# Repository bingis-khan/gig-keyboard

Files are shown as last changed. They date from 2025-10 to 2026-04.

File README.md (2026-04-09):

# My split keyboard

my cool split keyboard. contains OpenSCAD source files and the arduino project file.

keyboard top
keyboard bottom

## Compiling

To generate the STL files, run `./print-script.sh`, which exports the STL part files.

For programming the board, use:

```
  arduino-cli compile -ub rp2040:rp2040:waveshare_rp2040_pizero -p /dev/ttyACM0
```

## Special mapping

- Soya button + hjkl - arrows
- Soya + top row - numbers
- Soya + 250mL + top row - Fn keys.
- 250mL (without Soya) - left alt
- juice key + -.'= keys - mouse movement.
- juice key + jk - scroll
- juice key + ,l/ - left/middle/right mouse button click

## Notes for V2

- use a pcb next time - wire crosstalk problems (actually, probably single copper strands touching each other)
- with a pcb, try adding how-swappable sockets.
- use linear switches

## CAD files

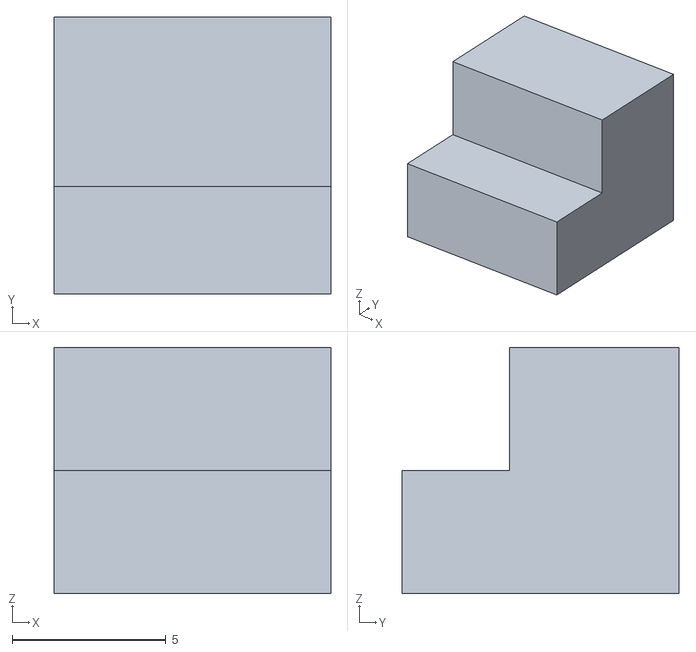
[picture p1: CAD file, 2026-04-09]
stl/third_leg.stl
9.00 x 9.00 x 8.00

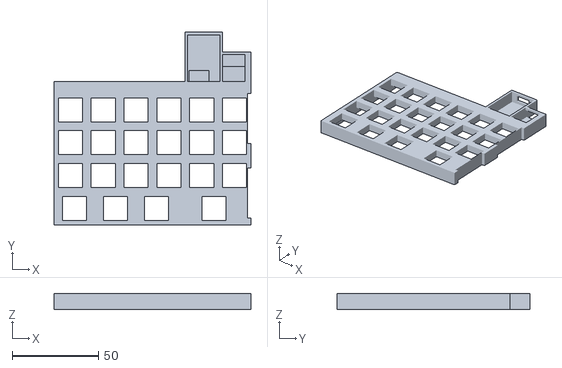
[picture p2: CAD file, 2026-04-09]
stl/left_part.stl
114.3 x 111.7 x 9.35

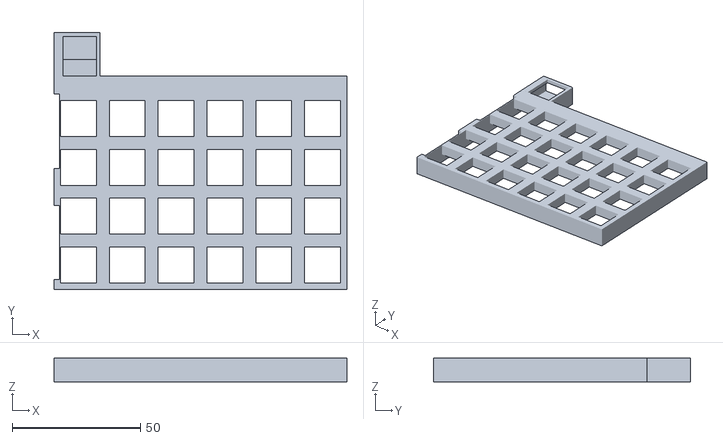
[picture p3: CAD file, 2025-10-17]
stl/right_part.stl
114.3 x 100.2 x 9.35

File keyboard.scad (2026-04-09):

$fa = 1;
$fs = 0.4;

print = false;  // may be redefined at command line


// right now, let's make a printable "slab" where I can insert the keys and put on keycaps to see if they fit.

// spacing: https://null-src.com/posts/keyboard-design-cheatsheet/
// apparently, 1u = 19.05mm

key_size = 14;
unit = 19.05;
key_pin = 3.3;  // from ref.
key_body = 5;
key_underside = key_pin + key_body;
key_off = (unit - key_size) / 2;

max_key_with_keycap_exact_height = 18;  // in mm. based on OEM num keys.
pressed_key_height = 11;  // close enough.
exposed_switch_height = 6;  // close enough
slump = exposed_switch_height;  // not sure how much to lower the keyboard plane. this variable tracks it.

// 2 parts. these numbers refer to one part.
keys_in_row = 6;
keys_in_column = 4;  // NOTE: last column is different.

use_width = keys_in_row * unit;
use_height = keys_in_column * unit;

cable_zone_height = 7;

off = 0;  // random offset, so that the part "sticks"

// if i decide to make the keyboard angled, this would be it.
key_plane_angle = 0;

avg_depth = 5;
cut_depth = 2;  // cutting shit


function sum(l, i = 0) =
    i < len(l)
        ? l[i] + sum(l, i + 1)
        : 0;

function slice(l, from, to) =
    to != undef  // HACK: if to is undefined, then we assume 'from' is actually 'to' and from is 0.
        ? to >= from  // when range is empty, make empty list yo.
            ? [for (i = [from : to]) l[i]]
            : []
        : slice(l, 0, from);

module key_plane_cutouts(edge_off, last_line) {
    key_begin = (unit - key_size) / 2;
    for (x = [key_begin : unit : use_width]) {
        // ignore closest key line
        for (y = [key_begin + unit : unit : use_height]) {
            translate([x + edge_off, y + edge_off, -cut_depth/2]) cube([key_size, key_size, avg_depth + cut_depth]);
        }
    }

    // add later lines
    last_line_units = [for (s = last_line) s * unit];
    for (i = [0 : len(last_line_units) - 1]) {
        spacing_until_now = sum(slice(last_line_units, i - 1));
        spacing = last_line_units[i];

        key_off = (spacing - key_size) / 2;

        x = edge_off + spacing_until_now + key_off;
        y = edge_off + key_begin;
        translate([x, y, -cut_depth/2]) cube([key_size, key_size, avg_depth + cut_depth]);
    }
}

module test_key_grid() {
    key_begin = (unit - key_size) / 2;
    for (x = [key_begin : unit : use_width]) {
        for (y = [key_begin : unit : use_height]) {
            translate([x + off, y + off, -cut_depth/2]) cube([key_size, key_size, avg_depth + cut_depth]);
        }
    }
   
}

module key_plane(edge_off, last_line) {
    part_width = use_width + 2*edge_off;
    height = use_height + 2*edge_off + cable_zone_height;
    difference() {
        cube([part_width, height, avg_depth]);
        
        key_plane_cutouts(edge_off, last_line);
        translate([key_off, height - cable_zone_height - conn_off, -conn_off]) cube([use_width - 2*key_off, cable_zone_height, avg_depth]);

        // right part.
        // key_plane([1.75, 1.25, 1, 1, 1, 1]);
    }
}


module flip_z() {
    scale([1, 1, -1]) children();
}

module flip_y() {
    scale([1, -1, 1]) children();
}

module flip_x() {
    scale([-1, 1, 1]) children();
}

module id() {
    children();
}

// half function half comment. used to mean that we cut FAR.
function farcut(x) =
    x != undef
        ? x + 1000
        : 1000;


rp_width = 24;
rp_height = 18.8;
rp_more = 3;  // elongate the thing, so you can put in the rpi easier.
usbc_width = 7;
usbc_height = 9 + 1;  // measured + error
usbc_z = 3 + 1;
rp_off = 1.5;

module rp2040() {
	cube([rp_width, rp_height, 1]);
	translate([-2, (rp_height  - 9) / 2, 1]) cube([usbc_width, usbc_height, usbc_z]);
}

wall_thickness = 10;
plane2ground = key_underside + 5;  // 5mm added to approximate the actual size of this keyboard.
front_back_wall_height = max_key_with_keycap_exact_height - slump;
left_right_wall_height = front_back_wall_height * 2;
max_height = plane2ground + left_right_wall_height;  // for now! we're not including the bottom layer yet.
echo("max height: ", max_height);
connection_off = 0;  // for connections with surrounding wall. not needed now.
extra = 1;
wall_down = key_underside - key_body + extra;

module part() {
			// keys
	    translate([0, 0, wall_down]) {
				children();

				// wallz
				flip_z() difference() {
					cube([use_width, use_height + cable_zone_height, wall_down]);

					translate([key_off, key_off, -.1]) cube([use_width - 2*key_off, use_height + cable_zone_height - 2*key_off, farcut()]);
				}
			}
}


pin = 3;  // got by measuring
conn_width = 5 * pin;
conn_height = 2 * pin;
conn_min_depth = 12;
conn_off = 1.5;

all_height = wall_down + 2*key_off;  // NOTE: does not make sense at all. it's my shitty coding, because I didn't bother to look through the code now.
thing_width = conn_width + 2 * conn_off;
thing_height = conn_height + 2 * conn_off;
thing_z = conn_min_depth + 5;

magnet_length = 28 + 1;
magnet_thickness = 2 + .1;  // minimal error - we are operating on scraps. very thin walls.
magnet_height = 9 + 1;

extra_off = 0;

module left_part() {
		difference() {
			id () {
		    part() key_plane(connection_off, [1.25, 1.25, 1.25, 2.25]);

				// magnet thing
				// magnet_thing_length = thing_z + cable_zone_height + key_off;
				// translate([use_width - extra_off, use_height - key_off, 0]) {
				// 	cube([extra_off, magnet_thing_length, all_height + 5]);
				// }


				// connector part
				translate([use_width - thing_width - extra_off, use_height + cable_zone_height, 0]) {
					difference() {
						cube([thing_width, thing_z, max(thing_height, all_height)]);

						// main shaft
						translate([conn_off, 0, conn_off]) cube([thing_width - 2*key_off, thing_z - conn_off, farcut()]);

						// pinout
						translate([conn_off, 0, conn_off]) cube([thing_width - 2*conn_off, farcut(), thing_height - 2*conn_off]);
					}
				}

				// arduino part
				rpp_width = rp_height + 2*rp_off;
				rpp_height = rp_width + rp_more + rp_off;
				translate([use_width - thing_width - rpp_width + rp_off - extra_off, use_height + cable_zone_height, 0]) {
					difference() {
						id() {
							cube([rpp_width, rpp_height, max(usbc_z + rp_off + 2 + rp_off, all_height)]);
						}

						// top shaft
						translate([rp_off, -.1, rp_off]) cube([rpp_width - 2*rp_off, rpp_height - rp_off, farcut()]);

						// usbc cutout
						translate([(rpp_width - usbc_height) / 2, 10, rp_off + 2]) cube([usbc_height, farcut(), usbc_z]);

						// main shaft
						// translate([key_off, 0, key_off]) cube([rpp_width - 2*key_off, rpp_height - key_off, farcut()]);

						// pinout
						// translate([key_off, 2*key_off, key_off]) cube([thing_width - 2*key_off, thing_z - key_off, thing_height - 2*key_off]);
					}
				}
			}

			// cut between wire connector and keyboard
			translate([use_width - thing_width + conn_off - extra_off, use_height + cable_zone_height - 2*conn_off - 4, conn_off - conn_off/2]) cube([key_size, thing_z - conn_off, thing_height - 2*conn_off + conn_off/2]);

			// rp - keyboard
			translate([use_width - thing_width - key_off/2 + key_off - .2 - unit - extra_off, use_height + cable_zone_height - 2*key_off - 3, key_off - key_off/2]) cube([key_size - key_off, thing_z - key_off, thing_height - 2*key_off + key_off/2]);

			// magnet hollow outs
			// NOTE: the magnet is as tall as the keyboard, so I'll do a vertical cut.
			// the magnet should be glued to it.
			translate([use_width - extra_off - magnet_thickness + 0.01, use_height - magnet_length, -0.01]) {
				cube([magnet_thickness, magnet_length, magnet_height]);
			}

			translate([use_width - extra_off - magnet_thickness + 0.01, key_off + key_off/2, -0.01]) {
				cube([magnet_thickness, magnet_length, magnet_height]);
			}
		}
}

module right_part() {
    flip_x() {
		difference() {
			id() {
		 part() key_plane(connection_off, [1, 1, 1, 1, 1, 1]);  // funny hack. i simply reversed the last line keys in a list and it works :3
		  
				// connector part
				translate([use_width - thing_width, use_height + cable_zone_height, 0]) {
					difference() {
						cube([thing_width, thing_z, max(thing_height, all_height)]);

						// main shaft
						translate([conn_off, 0, conn_off]) cube([thing_width - 2*key_off, thing_z - conn_off, farcut()]);

						// pinout
						translate([conn_off, 0, conn_off]) cube([thing_width - 2*conn_off, farcut(), thing_height - 2*conn_off]);
					}
				}
			}

			// cut between wire connector and keyboard
			translate([use_width - thing_width + conn_off, use_height + cable_zone_height - 2*key_off - 3, key_off - key_off/2]) cube([key_size, thing_z - key_off, thing_height - 2*key_off + key_off/2]);
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

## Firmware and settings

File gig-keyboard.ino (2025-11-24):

#include <Keyboard.h>
#include <Mouse.h>

// because we do pullup, the shit is actually reversed.
// So, unlike https://www.dribin.org/dave/keyboard/one_html/,
//  *we are powering up ROWS and reading COLUMNS.*

// QMK style defs for style
// ROWS (top - bottom):
#define ROWS { 0, 1, 2, 3 }
// LEFT COLUMNS (left-right):
// #define COLUMNS { 10, 4, 7, 6, 5, 8, 29, 28, 11, 26, 15, 14 }
#define COLUMNS { 14, 15, 26, 11, 28, 29, 8, 5, 6, 7, 4, 10 }
#define CHARS \
  { { KEY_ESC, 'q', 'w', 'e', 'r', 't',         'y', 'u', 'i', 'o', 'p', KEY_BACKSPACE  } \
  , { KEY_LEFT_CTRL, 'a', 's', 'd', 'f', 'g',   'h', 'j', 'k', 'l', ';', KEY_RETURN } \
  , { KEY_LEFT_SHIFT, 'z', 'x', 'c', 'v', 'b',  'n', 'm', ',', '.', '/', KEY_RIGHT_SHIFT } \
  , { KEY_LEFT_ALT, KEY_LEFT_GUI, NO_KEY, 0, ' ', NO_KEY,  ' ', KEY_RIGHT_ALT, '-', '=', '\'', 0 } \
  }

// special keyboard keys.

// num switch
#define NUM_SWITCH_PIN_IDS 3,3
// fn switch
#define FN_SWITCH_PIN_IDS 3,0
// mouse switch
#define JUICE_PIN_IDS 3,11
// where the numeric part begins.
#define NUM_BEGIN_CI 1
#define NUM_BEGIN_RI 0

const int rows[] = ROWS;
const int columns[] = COLUMNS;
#define ROWS_NUM (sizeof(rows)/sizeof(int))
#define COLUMNS_NUM (sizeof(columns)/sizeof(int))
#define NO_KEY ((char)0)


typedef struct {
  char key;
  char num_key;  // when NUM SWITCH is pressed.
  char fn_key;
  char last_pressed_key;  // NO_KEY or an actual key value.
} Key;

Key chars[ROWS_NUM][COLUMNS_NUM];


typedef struct {
  int last_moved;  // both up/down wheel. (a struct, because we might split it into last_moved_up/down)
} MouseWheel;

MouseWheel wheel;


void setup() {
  // set ROWS as OUTPUT
  for (int i = 0; i < ROWS_NUM; i++) {
    pinMode(rows[i], OUTPUT);
  }

  for (int i = 0; i < COLUMNS_NUM; i++) {
    pinMode(columns[i], INPUT_PULLUP);
  }

  // setup keys
  const char char_keys[ROWS_NUM][COLUMNS_NUM] = CHARS;
  for (int ri = 0; ri < ROWS_NUM; ri++) {
    for (int ci = 0; ci < COLUMNS_NUM; ci++) {
      char default_key = char_keys[ri][ci];

      // default case so that I won't have to change = and :
      // JUST LIKE MY HECKING HASKELLINO
      #define CASE false ? NO_KEY
      char num_key = CASE
          // arrows
          // im using vim style arrows now,
          // but my keyboard is on a "grid", so i can just
          // simulate normal arrows.
          //  Also, In this case there should be a toggle (the juice button?)
          : default_key == 'h' ? KEY_LEFT_ARROW
          : default_key == 'j' ? KEY_DOWN_ARROW
          : default_key == 'k' ? KEY_UP_ARROW
          : default_key == 'l' ? KEY_RIGHT_ARROW

          // ctrl -> tab
          // EDIT: this is hard... I use tab, but at the same time I want to use ctrl+arrow keys to move around a command.
          // EDIT: CHANGED LCTRL TO A.
          : default_key == 'a' ? KEY_TAB
          
          // backspace -> delete
          // EDIT: stupid idea - super annoying in practice. I'll leave DELETE unmapped for now.
          // : default_key == KEY_BACKSPACE ? KEY_DELETE

          // misc keys which didn't make the cut
          : default_key == '-' ? '['   // NOTE: not the < > keys, because they have '.' and ',' which are useful when writing decimal points.
          : default_key == '=' ? ']'
          : default_key == KEY_ESC ? '`'
          : default_key == '/' ? '\\'

          : ci >= NUM_BEGIN_CI && ci < (NUM_BEGIN_CI + 10) && ri == NUM_BEGIN_RI
            ? (char)('0' + ((ci - NUM_BEGIN_CI + 1) % 10))
          : default_key;

      char fn_key = CASE
          : default_key == KEY_LEFT_ALT ? NO_KEY  // if both FN and NUM are pressed, release LALT. (BUG: lettuing go of NUM does not repress the LALT.)
                                                  // why?  when LALT is pressed in firefox, PGUP and PGDOWN don't work.

          : default_key == 'j' ? KEY_PAGE_DOWN
          : default_key == 'k' ? KEY_PAGE_UP

          // HACK to enable CTRL + LEFT/RIGHT ARROW in terminal and controls
          : default_key == KEY_LEFT_CTRL ? KEY_LEFT_CTRL

          : ci >= NUM_BEGIN_CI && ci < (NUM_BEGIN_CI + 10) && ri == NUM_BEGIN_RI
            ? ((char)(KEY_F1 + (ci - NUM_BEGIN_CI)))  // NOTE: formula works until F12 (https://docs.arduino.cc/language-reference/en/functions/usb/Keyboard/keyboardModifiers/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)
          : num_key;

      chars[ri][ci] = (Key) {
        .key = default_key,
        .num_key = num_key,
        .fn_key = fn_key,
        .last_pressed_key = NO_KEY,
      };
    }
  }


  // mouse init
  wheel.last_moved = millis();

  Keyboard.begin();
  Mouse.begin();
  Serial.begin(115200);
}

void loop() {
  // read special modifier keys
  bool num_switch = quick_check(NUM_SWITCH_PIN_IDS);
  bool special_switch = quick_check(FN_SWITCH_PIN_IDS);
  bool mouse_switch = quick_check(JUICE_PIN_IDS);

  if (!mouse_switch) {
    unpress_mouse();
  }


  // read keyboard in general
  {
    for (int ri = 0; ri < ROWS_NUM; ri++) {
      const int r = rows[ri];
      digitalWrite(r, LOW);
      for (int ci = 0; ci < COLUMNS_NUM; ci++) {
        const int c = columns[ci];

        Key *const k = &chars[ri][ci];


        const char key
          = special_switch && num_switch ? k->fn_key
          : num_switch ? k->num_key
          : k->key;

        // TODO: some logic restructure (key release in two places - kinda cringe)
        // ANOTHER TODO: make use of internal keyboard structure and eliminate last_pressed_key (and change it to isPressed? maybe less bugs, but more calls, as we're asking for each key)
        if ((k->last_pressed_key != key || (mouse_switch && ci >= 6)) && k->last_pressed_key != NO_KEY) {
          Keyboard.release(k->last_pressed_key);
        }

        // special mouse escape hatch.
        if (mouse_switch && ci >= 6) {  // NOTE: mouse look hack. because we're using only the right side (except modifiers), we can use the left side as a normal keyboard. this makes it possible to sorta play videogames with mouse look.
          handle_mouse(num_switch, special_switch, c, k);
          continue;
        }

        if (key == NO_KEY) {
          continue;
        }

        // HACK mouse look: don't press lalt when juiced
        if (key == KEY_LEFT_ALT && mouse_switch) {
          continue;
        }

        const bool pressed = digitalRead(c) == LOW;
        if (k->last_pressed_key != key && pressed) Keyboard.press(key);
        if (k->last_pressed_key != NO_KEY && !pressed) Keyboard.release(k->last_pressed_key);
        k->last_pressed_key = pressed ? key : NO_KEY;
      }
      digitalWrite(r, HIGH);
    }
  }

  delay(10);  // this seems to be enough for debouncing.
}


static void handle_mouse(bool slower, bool faster, int c, Key *const k) {
  const bool pressed = digitalRead(c) == LOW;

  int cursor_speed = CASE
    : slower && !faster ? 1
    : faster && !slower ? 12
    : 5;
    // with my experiments, I don't think we need a fourth speed.

  int wheel_delay = CASE
    : slower && !faster ? 200
    : !slower && faster ? 10
    : 40;
  
  switch (k->key) {
    // mouse wheel
    // speed 1 is already plenty fast
    case 'j': {
      int t = millis();
      if (pressed && t - wheel.last_moved >= wheel_delay) {
        Mouse.move(0, 0, -1);
        wheel.last_moved = t;
      }
    } break;
    case 'k': {
      int t = millis();
      if (pressed && t - wheel.last_moved >= wheel_delay) {
        Mouse.move(0, 0, 1);
        wheel.last_moved = t;
      }
    } break;

    // cursor movement
    case '.': {
        if (pressed) Mouse.move(0, -cursor_speed);
    }; break;
    case '=': {
        if (pressed) Mouse.move(0, cursor_speed);
    }; break;
    case '-': {
        if (pressed) Mouse.move(-cursor_speed, 0);
    }; break;
    case '\'': {
        if (pressed) Mouse.move(cursor_speed, 0);
    }; break;

    // cursor buttons
    // TD: maybe just call a function...
    case ',': {
        handle_press(pressed, MOUSE_LEFT);
    } break;
    case 'l': {
        handle_press(pressed, MOUSE_MIDDLE);
    } break;
    case '/': {
        handle_press(pressed, MOUSE_RIGHT);
    } break;
  }
}

static void handle_press(bool pressed, int mb) {
  if (pressed && !Mouse.isPressed(mb)) Mouse.press(mb);
  else if (!pressed && Mouse.isPressed(mb)) Mouse.release(mb);
}

static void unpress_mouse() {
  if (Mouse.isPressed(MOUSE_LEFT))   Mouse.release(MOUSE_LEFT);
  if (Mouse.isPressed(MOUSE_MIDDLE)) Mouse.release(MOUSE_MIDDLE);
  if (Mouse.isPressed(MOUSE_RIGHT))  Mouse.release(MOUSE_RIGHT);
}


// geg
static bool quick_check(int ri, int ci) {
  const int r = rows[ri];
  digitalWrite(r, LOW);

  const int c = columns[ci];
  const char key = chars[ri][ci].key;
  const bool pressed = digitalRead(c) == LOW;

  digitalWrite(r, HIGH);
  return pressed;
}

// meant to work with the "pair" #defines.
static bool is_pair_equal(int r1, int c1, int r2, int c2) {
  return r1 == r2 && c1 == c2;
}

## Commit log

2025-11-24 increase size of MCU slot and remap pins for new soldering configuration
    [keyboard.scad, left_part.stl]
2026-04-09 update README, add images and regenerate stls
    [keyboard.scad, left_part.stl, third_leg.stl]
